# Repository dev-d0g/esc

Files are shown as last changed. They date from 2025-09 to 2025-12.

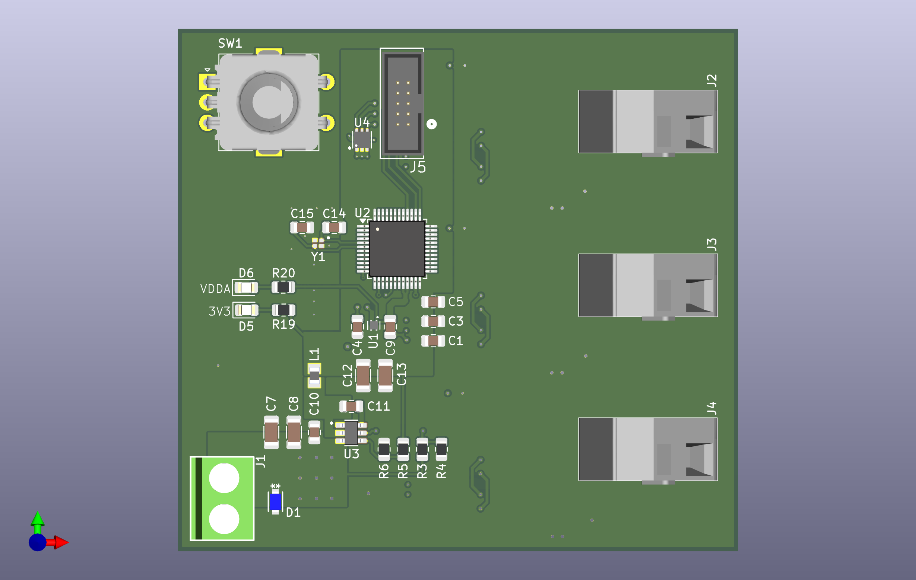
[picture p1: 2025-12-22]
top-view.png

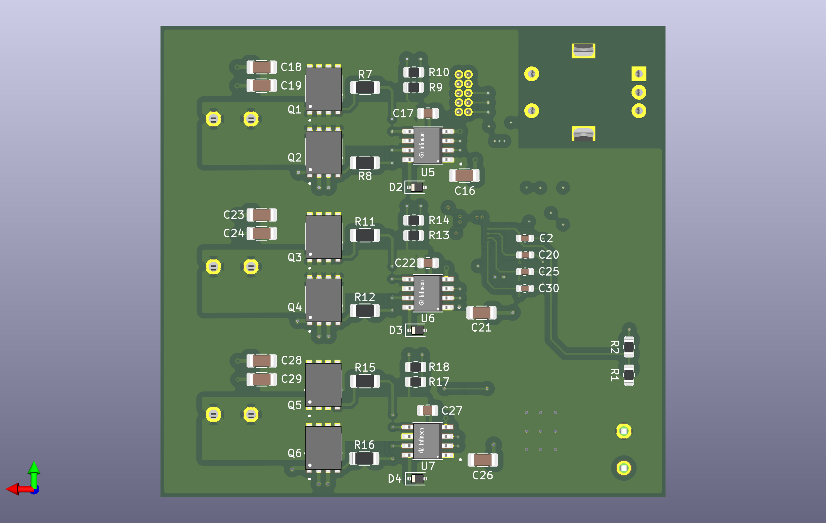
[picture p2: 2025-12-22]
bottom-view.png

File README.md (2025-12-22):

4 layer STM32-based trapezoidal ESC with high/low-side PWM control
top-view
bottom-view

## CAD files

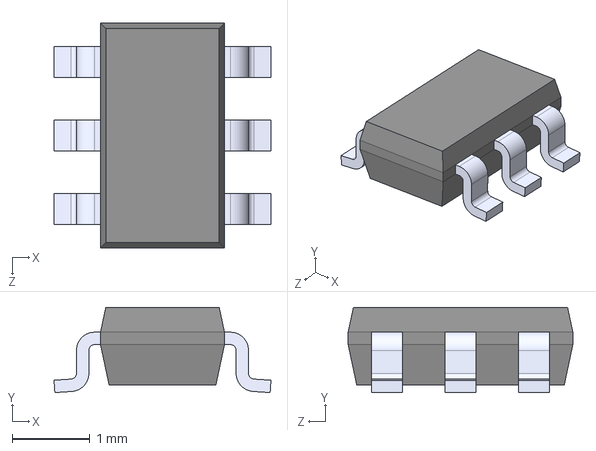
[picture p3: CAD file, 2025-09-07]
Digikey Downloads/Buck Converters/TPS562201DDCR/TPS562201DDCR.step
2.80 x 1.10 x 2.90 mm

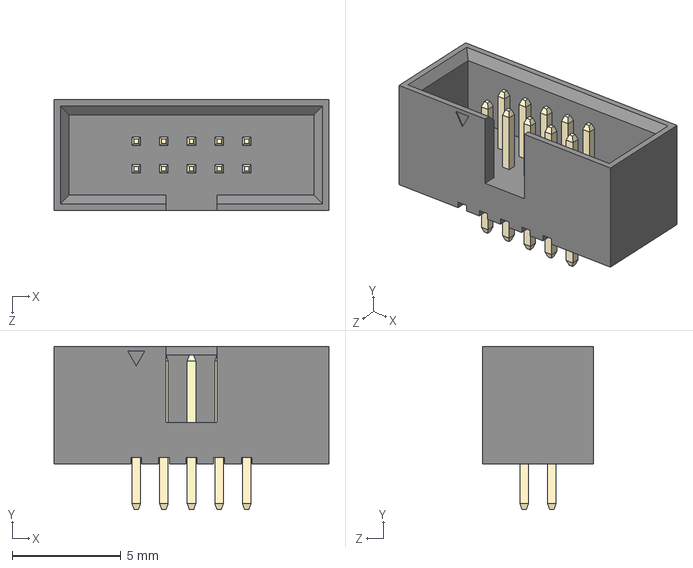
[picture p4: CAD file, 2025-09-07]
Digikey Downloads/Connectors/3220_10_0100_00_3D-model/3220-10-0100-00.STEP
12.7 x 7.50 x 5.10 mm
3220-xx-0100-00 body_10
Pin^3220-xx-0100-00 x 10

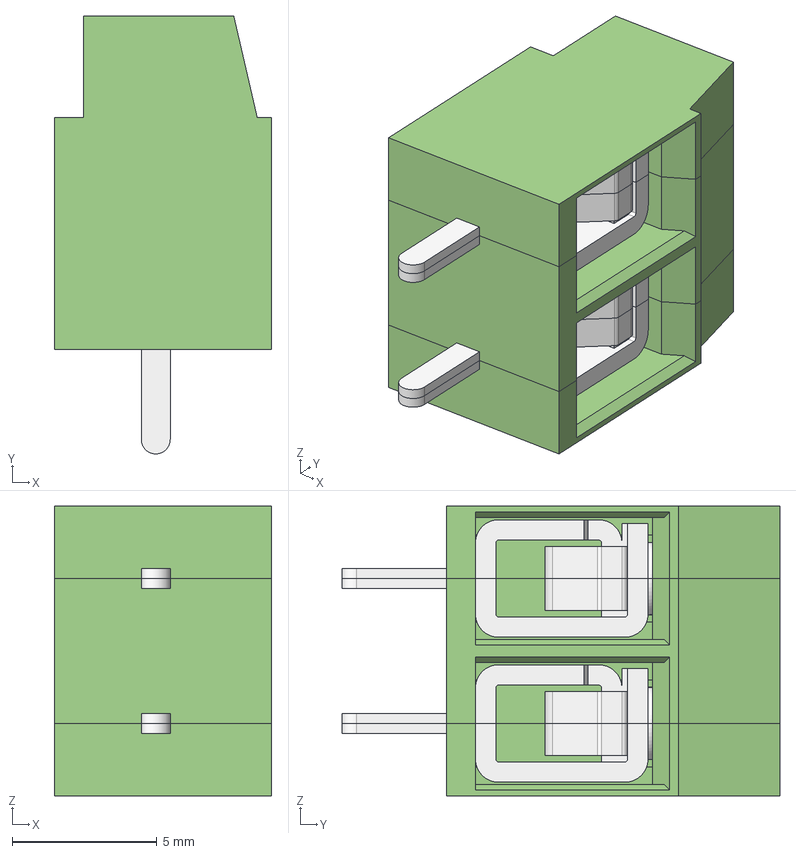
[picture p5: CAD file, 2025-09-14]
Digikey Downloads/Connectors/691137710002/691137710002.step
7.50 x 15.1 x 10.0 mm
MRT12P5_SX
MRT12P5_CNT
MRT12P5_DX

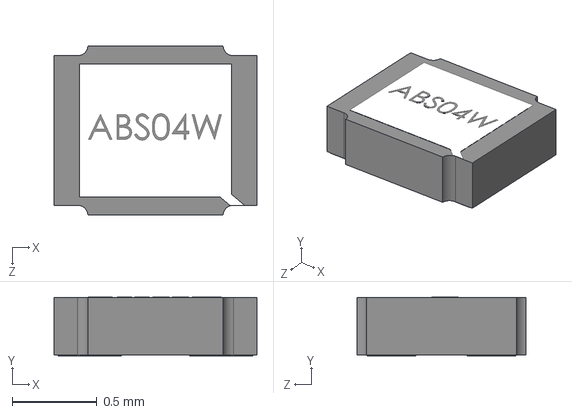
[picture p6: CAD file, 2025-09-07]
Digikey Downloads/Crystals/ABS04W_32_768KHZ_4_D2_T5/ABS04W-32.768KHZ-4-D2-T5.STEP
1.20 x 0.347 x 1.00 mm

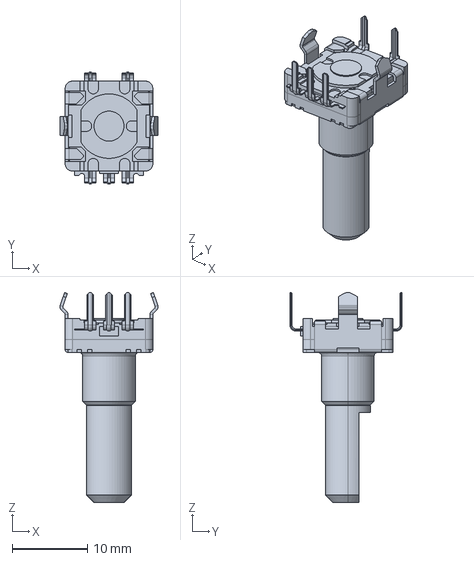
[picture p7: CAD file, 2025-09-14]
Digikey Downloads/Encoders/EC11E15204A3/ec11e15204a3.stp
13.1 x 15.0 x 28.0 mm

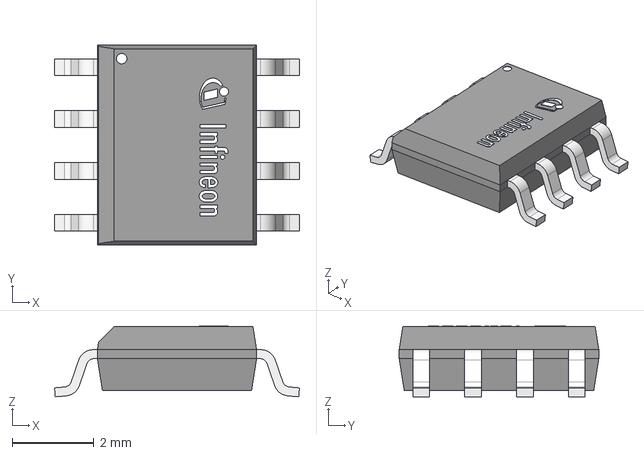
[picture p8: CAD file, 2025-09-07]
Digikey Downloads/Gate Drivers/IR2103STRPBF/PG-DSO-8-910.stp
6.00 x 4.89 x 1.73 mm

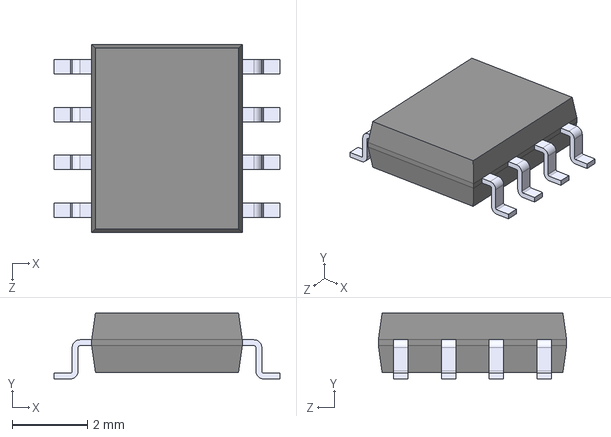
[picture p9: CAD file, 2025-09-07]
Digikey Downloads/Gate Drivers/IR2103STRPBF_Symbol-LandPattern/IR2103STRPBF.step
6.00 x 1.75 x 5.00 mm

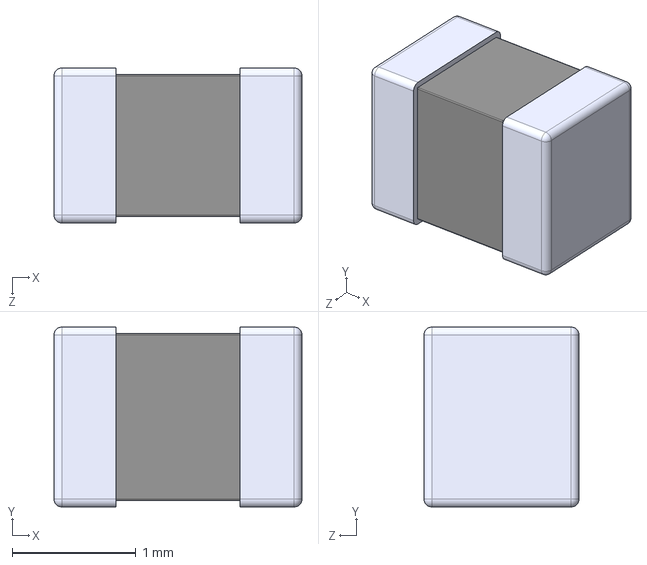
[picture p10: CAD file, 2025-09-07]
Digikey Downloads/Inductors/MLZ2012M3R3ATD69 (1)/MLZ2012M3R3ATD69.step
2.00 x 1.45 x 1.25 mm

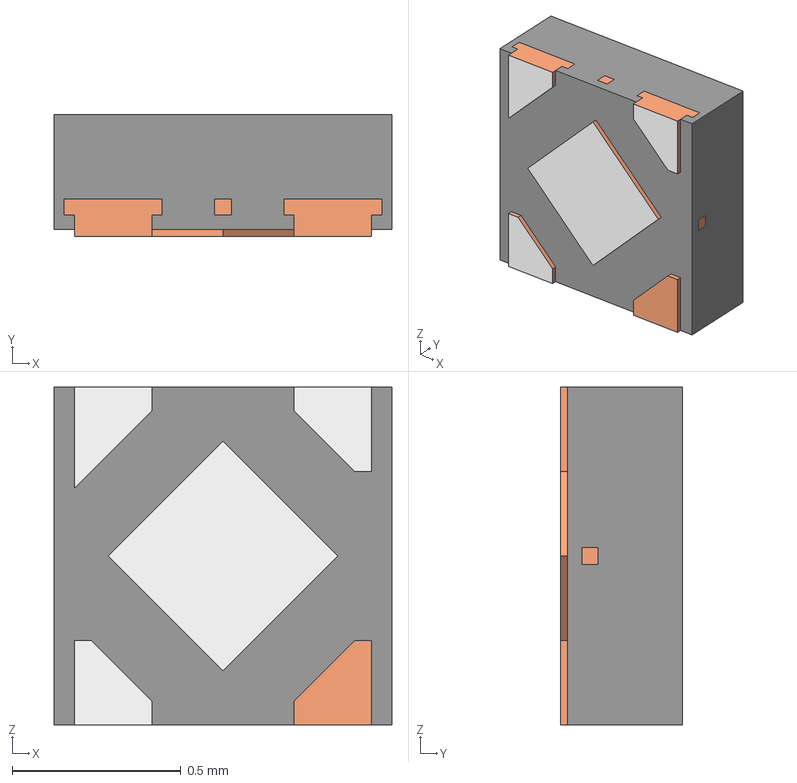
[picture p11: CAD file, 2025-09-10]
Digikey Downloads/LDOs/ul_PTPS7A20185PDQNR/DQN0004A.stp
1.00 x 0.36 x 1.00 mm
MOLD-SNB04A
FRAME-SNB04A

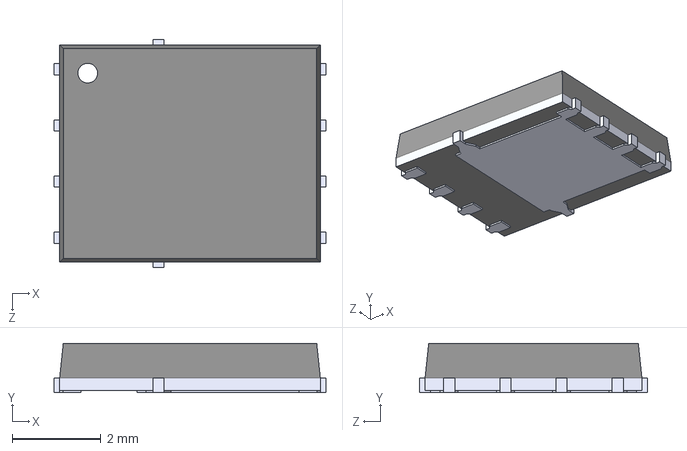
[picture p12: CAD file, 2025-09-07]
Digikey Downloads/MOSFETs/SIR182DP_T1_RE3 (1)/SIR182DP-T1-RE3.step
6.15 x 1.12 x 5.16 mm

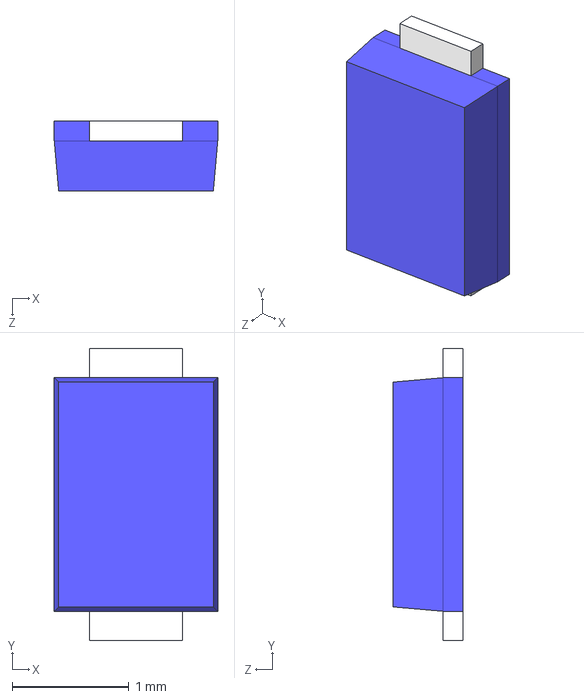
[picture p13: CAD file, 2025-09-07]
Digikey Downloads/TVS Diodes/CUHZ16V_H3F/US2H.STEP
1.40 x 2.50 x 0.6 mm

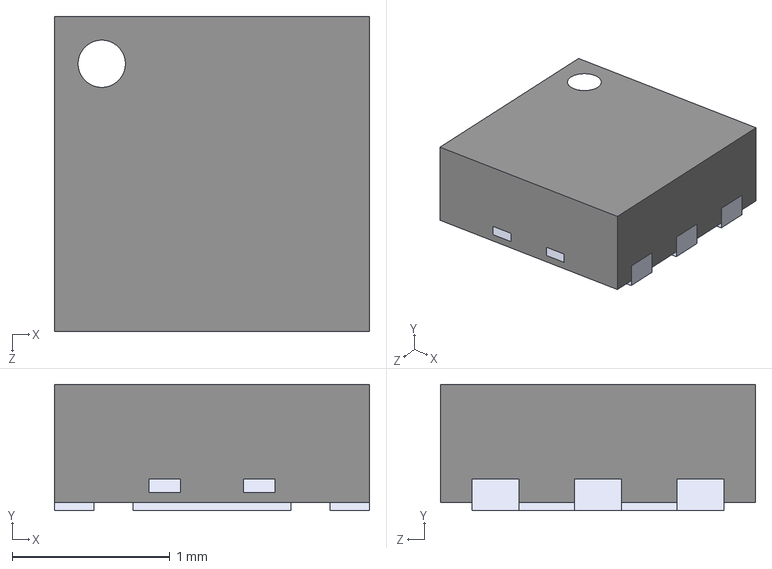
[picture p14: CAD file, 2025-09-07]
Digikey Downloads/TVS Diodes/TVS0500DRVR/TVS0500DRVR.step
2.00 x 0.8 x 2.00 mm

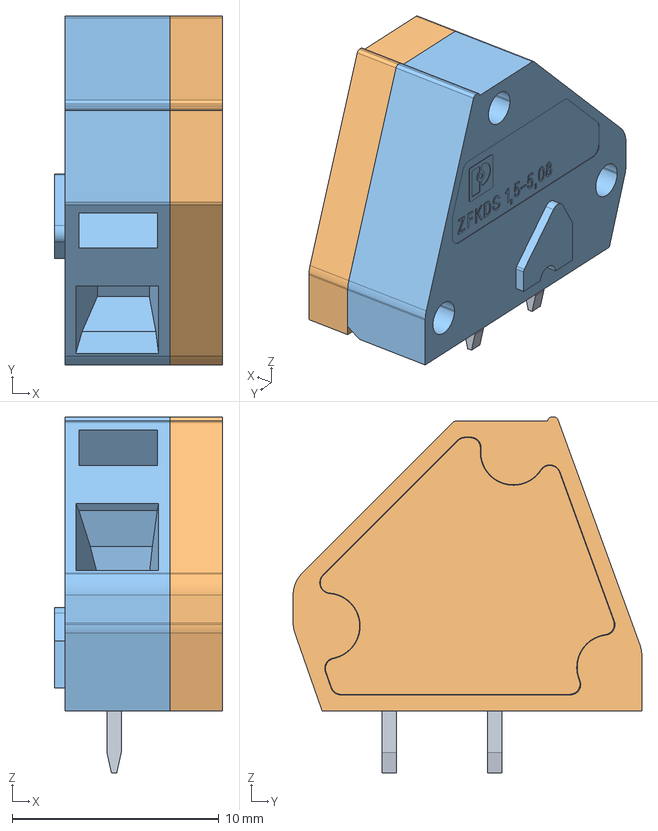
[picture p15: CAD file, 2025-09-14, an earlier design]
Digikey Downloads/Connectors/1706701 (1)/1706701.stp
8.12 x 16.9 x 17.2 mm

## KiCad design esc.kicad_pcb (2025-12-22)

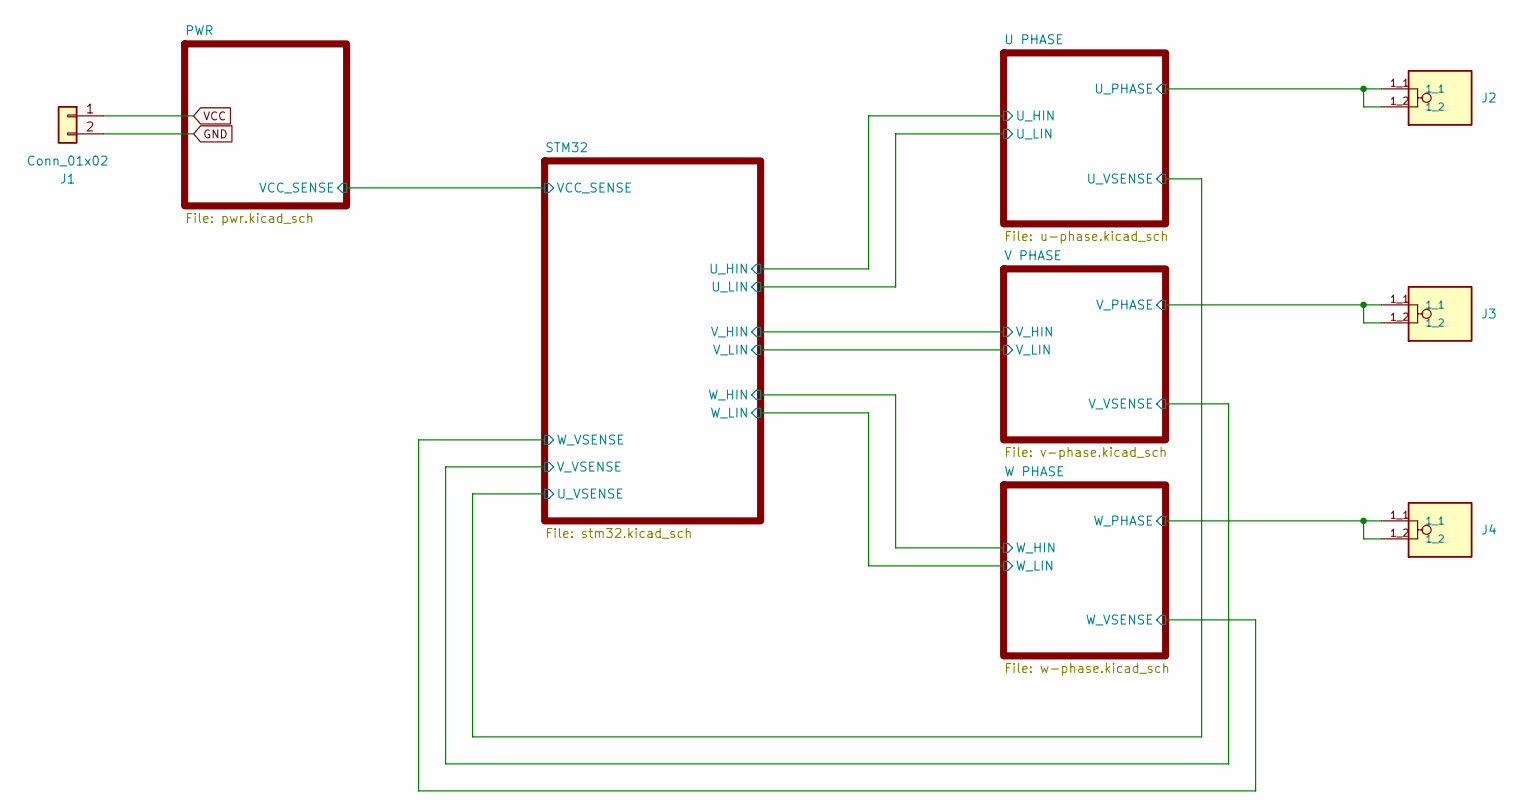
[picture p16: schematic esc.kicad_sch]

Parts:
J1: Conn_01x02; JWT_A3963_1x02_P3.96mm_Vertical
J2, J3, J4: Screw_Terminal_01x01; PHOENIX_1706701; PARTREV 24.09.2015

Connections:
/U PHASE/U_PHASE: J2.1_1, J2.1_2; also elsewhere on the board
/V PHASE/V_PHASE: J3.1_1, J3.1_2; also elsewhere on the board
/W PHASE/W_PHASE: J4.1_1, J4.1_2; also elsewhere on the board
GND: J1.2; also elsewhere on the board
VCC: J1.1; also elsewhere on the board

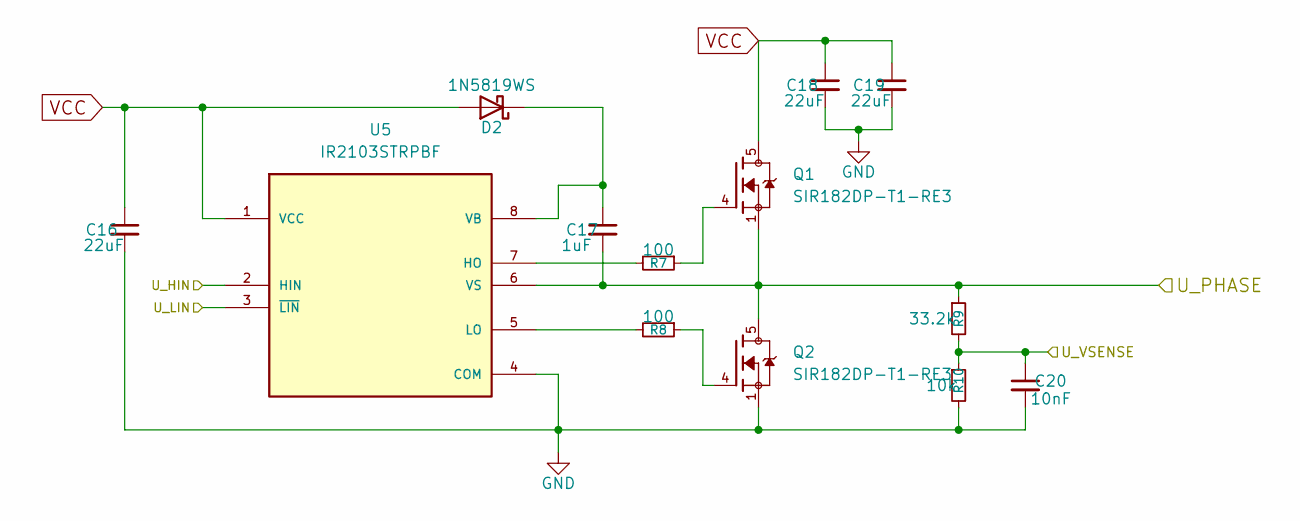
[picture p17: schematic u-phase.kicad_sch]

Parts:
C16, C18, C19: 22uF; C_1206_3216Metric
C17: 1uF; C_0805_2012Metric
C20: 10nF; C_0603_1608Metric
D2: 1N5819WS; D_SOD-323
Q1, Q2: SIR182DP-T1-RE3; TRANS_SIR182DP-T1-RE3; PARTREV B
R7, R8: 100; R_1206_3216Metric
R9: 33.2k; R_0805_2012Metric
R10: 10k; R_0805_2012Metric
U5: IR2103STRPBF; SOIC127P600X175-8N; PARTREV April 18, 2013

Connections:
/STM32/U_HIN: U5.2 (HIN); also elsewhere on the board
/STM32/U_LIN: U5.3 (~LIN); also elsewhere on the board
/STM32/U_VSENSE: C20.1, R9.2, R10.1; also elsewhere on the board
/U PHASE/U_PHASE: C17.2, Q1.1, Q1.2, Q1.3, Q2.5, Q2.6, Q2.7, Q2.8, Q2.9, R9.1, U5.6 (VS); also elsewhere on the board
GND: C16.2, C18.2, C19.2, C20.2, Q2.1, Q2.2, Q2.3, R10.2, U5.4 (COM); also elsewhere on the board
unnamed: C17.1, D2.1 (K), U5.8 (VB)
unnamed: Q1.4, R7.1
unnamed: Q2.4, R8.1
unnamed: R7.2, U5.7 (HO)
unnamed: R8.2, U5.5 (LO)
VCC: C16.1, C18.1, C19.1, D2.2 (A), Q1.5, Q1.6, Q1.7, Q1.8, Q1.9, U5.1 (VCC); also elsewhere on the board

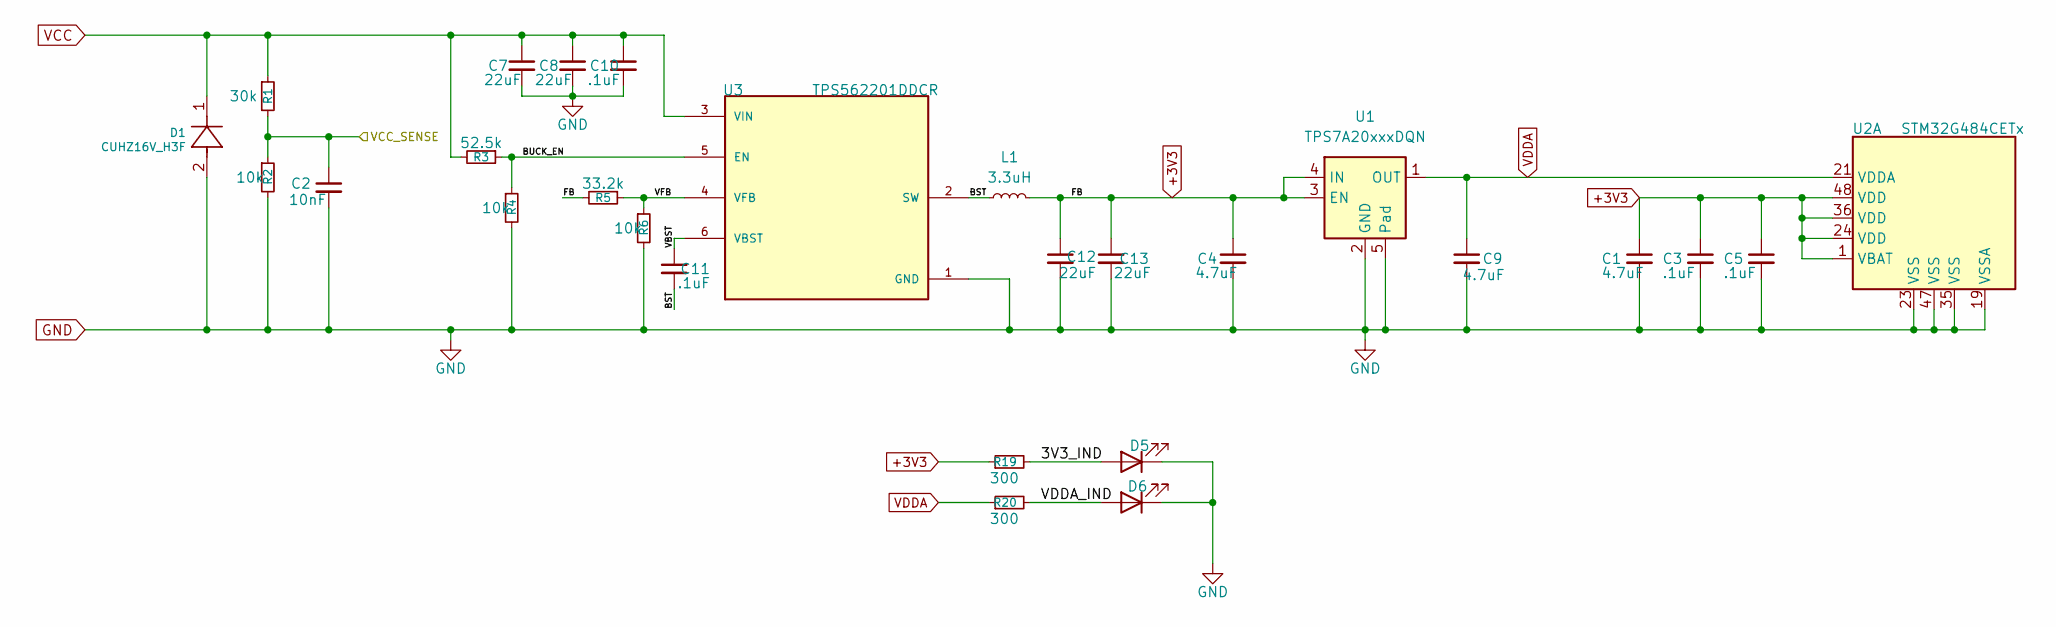
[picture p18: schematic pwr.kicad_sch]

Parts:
C1, C4, C9: 4.7uF; C_0805_2012Metric
C2: 10nF; C_0603_1608Metric
C3, C5, C10, C11: .1uF; C_0805_2012Metric
C7, C8, C12, C13: 22uF; C_1206_3216Metric
D1: CUHZ16V_H3F; SOD-323HEUS2H_TOS
D5, D6: LED; LED_0805_2012Metric
L1: 3.3uH; INDC2012X145N
R1: 30k; R_0805_2012Metric
R2, R4, R6: 10k; R_0805_2012Metric
R3: 52.5k; R_0805_2012Metric
R5: 33.2k; R_0805_2012Metric
R19, R20: 300; R_0805_2012Metric
U1: TPS7A20xxxDQN; Texas_X2SON-4_1x1mm_P0.65mm
U2: STM32G484CETx; LQFP-48_7x7mm_P0.5mm
U3: TPS562201DDCR; SOT95P280X110-6N; PARTREV A

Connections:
+3V3: C1.1, C3.1, C4.1, C5.1, C12.1, C13.1, L1.2, R5.2, R19.1, U1.3 (EN), U1.4 (IN), U2.1 (VBAT), U2.24 (VDD), U2.36 (VDD), U2.48 (VDD); also elsewhere on the board
/PWR/3V3_IND: D5.2 (A), R19.2
/PWR/BST: C11.2, L1.1, U3.2 (SW)
/PWR/BUCK_EN: R3.1, R4.1, U3.5 (EN)
/PWR/VBST: C11.1, U3.6 (VBST)
/PWR/VCC_SENSE: C2.1, R1.2, R2.1; also elsewhere on the board
/PWR/VDDA_IND: D6.2 (A), R20.2
/PWR/VFB: R5.1, R6.1, U3.4 (VFB)
GND: C1.2, C2.2, C3.2, C4.2, C5.2, C7.2, C8.2, C9.2, C10.2, C12.2, C13.2, D1.2, D5.1 (K), D6.1 (K), R2.2, R4.2, R6.2, U1.2 (GND), U1.5 (Pad), U2.19 (VSSA), U2.23 (VSS), U2.35 (VSS), U2.47 (VSS), U3.1 (GND); also elsewhere on the board
VCC: C7.1, C8.1, C10.1, D1.1, R1.1, R3.2, U3.3 (VIN); also elsewhere on the board
VDDA: C9.1, R20.1, U1.1 (OUT), U2.21 (VDDA); also elsewhere on the board

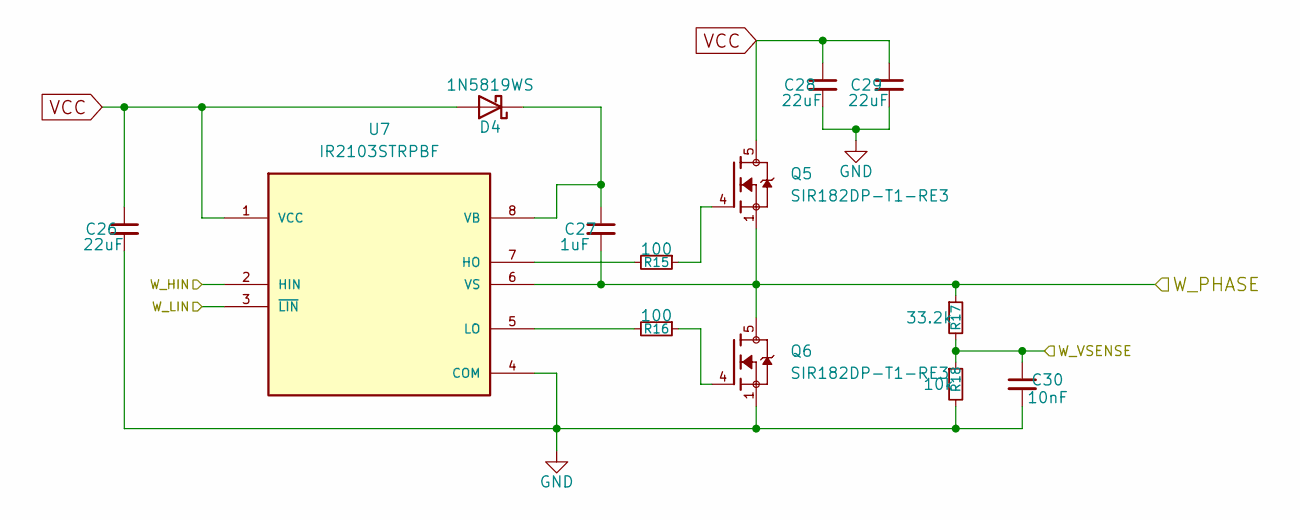
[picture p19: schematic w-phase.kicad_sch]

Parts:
C26, C28, C29: 22uF; C_1206_3216Metric
C27: 1uF; C_0805_2012Metric
C30: 10nF; C_0603_1608Metric
D4: 1N5819WS; D_SOD-323
Q5, Q6: SIR182DP-T1-RE3; TRANS_SIR182DP-T1-RE3; PARTREV B
R15, R16: 100; R_1206_3216Metric
R17: 33.2k; R_0805_2012Metric
R18: 10k; R_0805_2012Metric
U7: IR2103STRPBF; SOIC127P600X175-8N; PARTREV April 18, 2013

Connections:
/STM32/W_HIN: U7.2 (HIN); also elsewhere on the board
/STM32/W_LIN: U7.3 (~LIN); also elsewhere on the board
/STM32/W_VSENSE: C30.1, R17.2, R18.1; also elsewhere on the board
/W PHASE/W_PHASE: C27.2, Q5.1, Q5.2, Q5.3, Q6.5, Q6.6, Q6.7, Q6.8, Q6.9, R17.1, U7.6 (VS); also elsewhere on the board
GND: C26.2, C28.2, C29.2, C30.2, Q6.1, Q6.2, Q6.3, R18.2, U7.4 (COM); also elsewhere on the board
unnamed: C27.1, D4.1 (K), U7.8 (VB)
unnamed: Q5.4, R15.1
unnamed: Q6.4, R16.1
unnamed: R15.2, U7.7 (HO)
unnamed: R16.2, U7.5 (LO)
VCC: C26.1, C28.1, C29.1, D4.2 (A), Q5.5, Q5.6, Q5.7, Q5.8, Q5.9, U7.1 (VCC); also elsewhere on the board

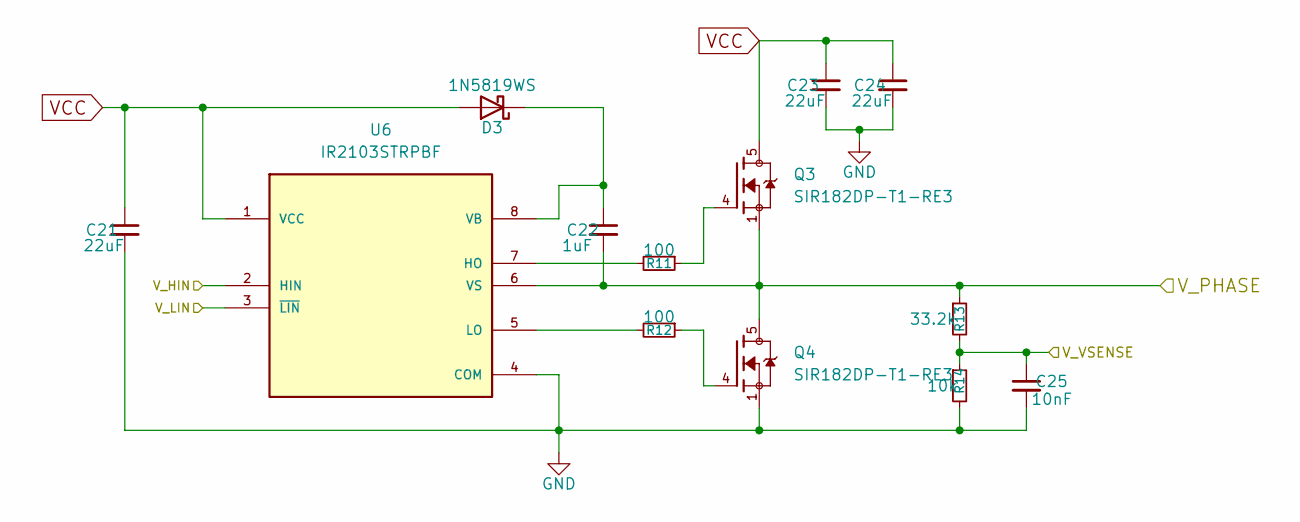
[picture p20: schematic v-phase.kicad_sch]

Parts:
C21, C23, C24: 22uF; C_1206_3216Metric
C22: 1uF; C_0805_2012Metric
C25: 10nF; C_0603_1608Metric
D3: 1N5819WS; D_SOD-323
Q3, Q4: SIR182DP-T1-RE3; TRANS_SIR182DP-T1-RE3; PARTREV B
R11, R12: 100; R_1206_3216Metric
R13: 33.2k; R_0805_2012Metric
R14: 10k; R_0805_2012Metric
U6: IR2103STRPBF; SOIC127P600X175-8N; PARTREV April 18, 2013

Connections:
/STM32/V_HIN: U6.2 (HIN); also elsewhere on the board
/STM32/V_LIN: U6.3 (~LIN); also elsewhere on the board
/STM32/V_VSENSE: C25.1, R13.2, R14.1; also elsewhere on the board
/V PHASE/V_PHASE: C22.2, Q3.1, Q3.2, Q3.3, Q4.5, Q4.6, Q4.7, Q4.8, Q4.9, R13.1, U6.6 (VS); also elsewhere on the board
GND: C21.2, C23.2, C24.2, C25.2, Q4.1, Q4.2, Q4.3, R14.2, U6.4 (COM); also elsewhere on the board
unnamed: C22.1, D3.1 (K), U6.8 (VB)
unnamed: Q3.4, R11.1
unnamed: Q4.4, R12.1
unnamed: R11.2, U6.7 (HO)
unnamed: R12.2, U6.5 (LO)
VCC: C21.1, C23.1, C24.1, D3.2 (A), Q3.5, Q3.6, Q3.7, Q3.8, Q3.9, U6.1 (VCC); also elsewhere on the board

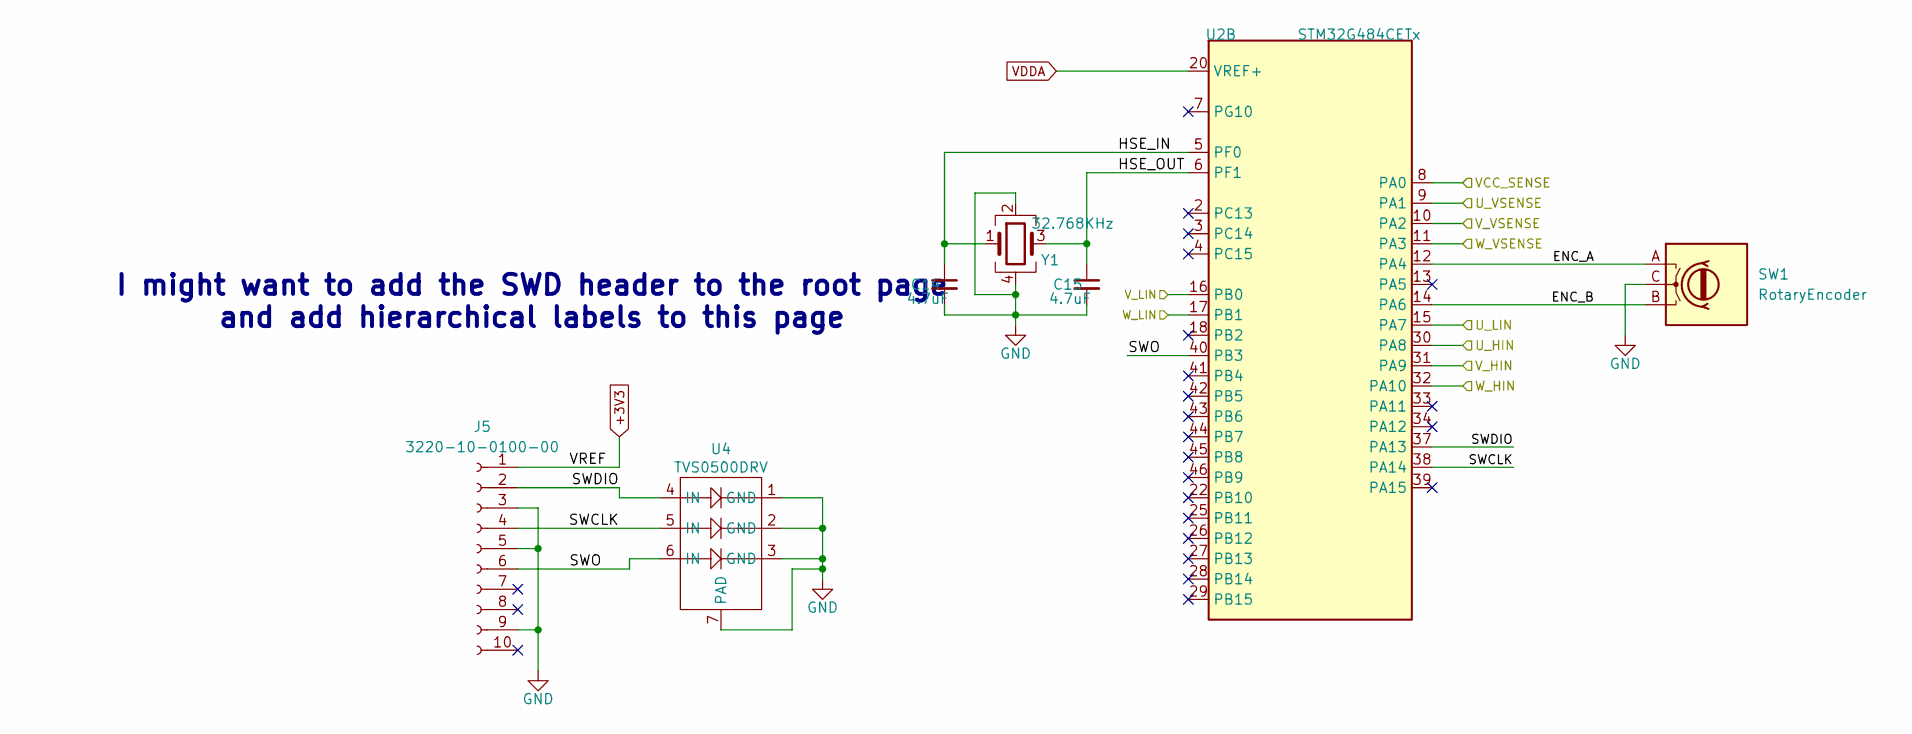
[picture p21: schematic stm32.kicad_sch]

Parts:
C14, C15: 4.7uF; C_0805_2012Metric
J5: 3220-10-0100-00; CONN_3220-10-0100-00_CNC
SW1: RotaryEncoder; RotaryEncoder_Alps_EC11E-Switch_Vertical_H20mm
U2: STM32G484CETx; LQFP-48_7x7mm_P0.5mm
U4: TVS0500DRV; SON65P200X200X80-7N
Y1: 32.768KHz; XTAL_ABS04W-32.768KHZ-4-D2-T5; PARTREV 12.18.2018

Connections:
+3V3: J5.1; also elsewhere on the board
/PWR/VCC_SENSE: U2.8 (PA0); also elsewhere on the board
/STM32/ENC_A: SW1.A, U2.12 (PA4)
/STM32/ENC_B: SW1.B, U2.14 (PA6)
/STM32/HSE_IN: C14.1, U2.5 (PF0), Y1.1
/STM32/HSE_OUT: C15.1, U2.6 (PF1), Y1.3
/STM32/SWCLK: J5.4, U2.38 (PA14), U4.5 (IN)
/STM32/SWDIO: J5.2, U2.37 (PA13), U4.4 (IN)
/STM32/SWO: J5.6, U2.40 (PB3), U4.6 (IN)
/STM32/U_HIN: U2.30 (PA8); also elsewhere on the board
/STM32/U_LIN: U2.15 (PA7); also elsewhere on the board
/STM32/U_VSENSE: U2.9 (PA1); also elsewhere on the board
/STM32/V_HIN: U2.31 (PA9); also elsewhere on the board
/STM32/V_LIN: U2.16 (PB0); also elsewhere on the board
/STM32/V_VSENSE: U2.10 (PA2); also elsewhere on the board
/STM32/W_HIN: U2.32 (PA10); also elsewhere on the board
/STM32/W_LIN: U2.17 (PB1); also elsewhere on the board
/STM32/W_VSENSE: U2.11 (PA3); also elsewhere on the board
GND: C14.2, C15.2, J5.3, J5.5, J5.9, SW1.C, U4.1 (GND), U4.2 (GND), U4.3 (GND), U4.7 (PAD), Y1.2, Y1.4; also elsewhere on the board
VDDA: U2.20 (VREF+); also elsewhere on the board

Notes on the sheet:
I might want to add the SWD header to the root page and add hierarchical labels to this page

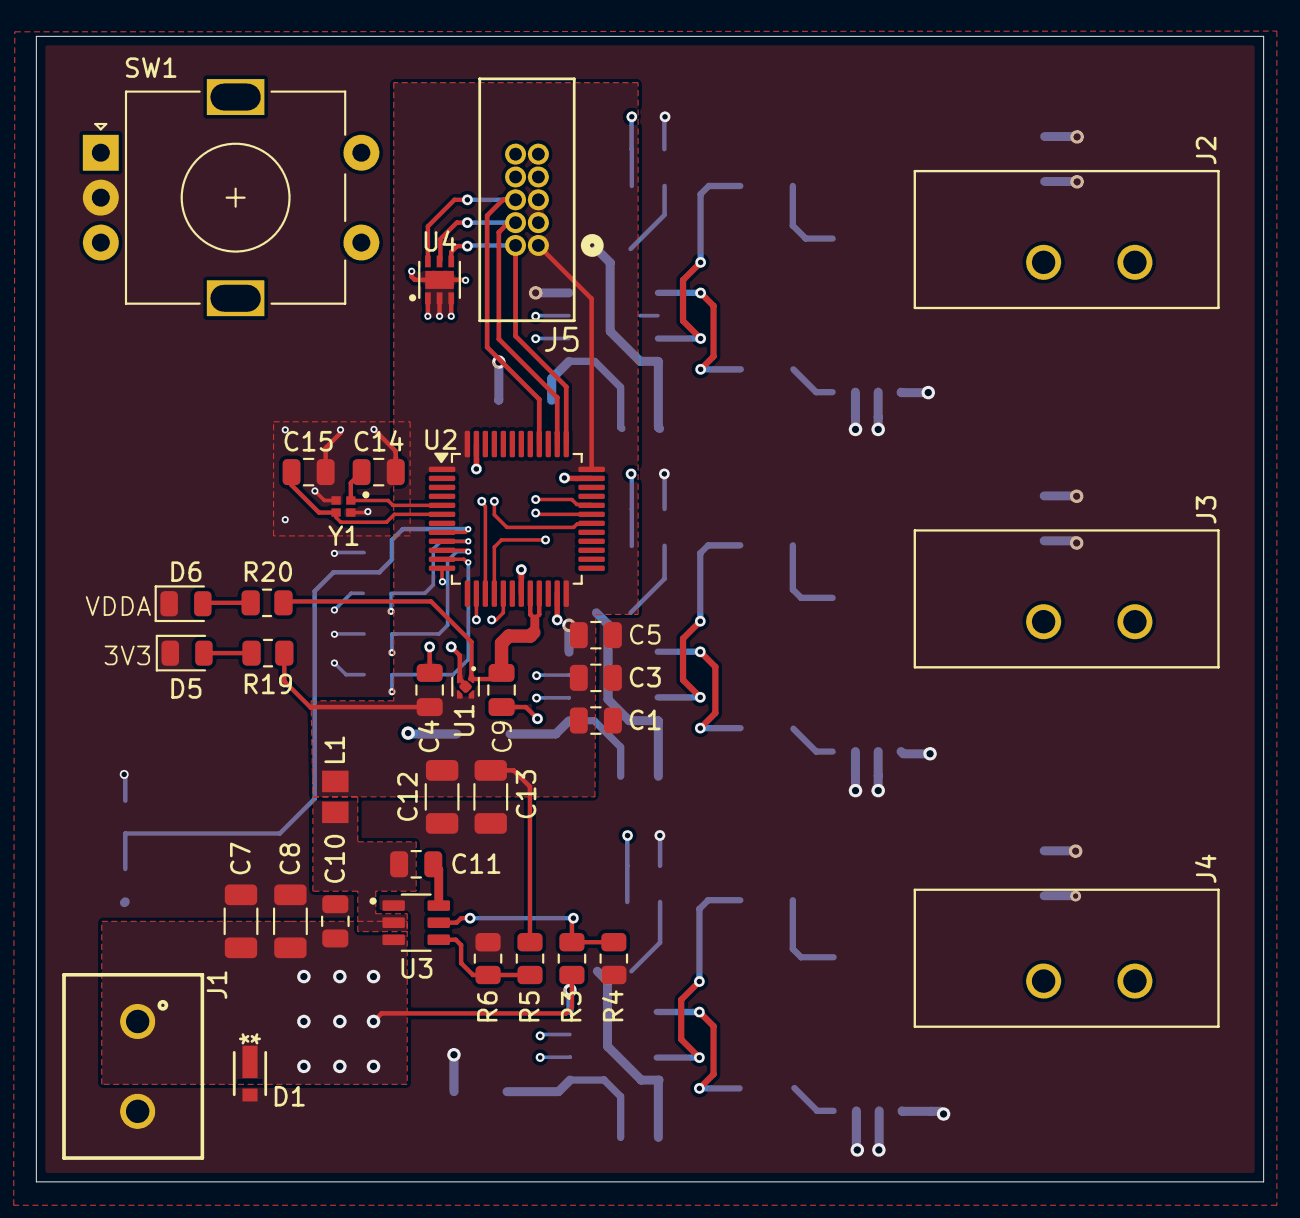
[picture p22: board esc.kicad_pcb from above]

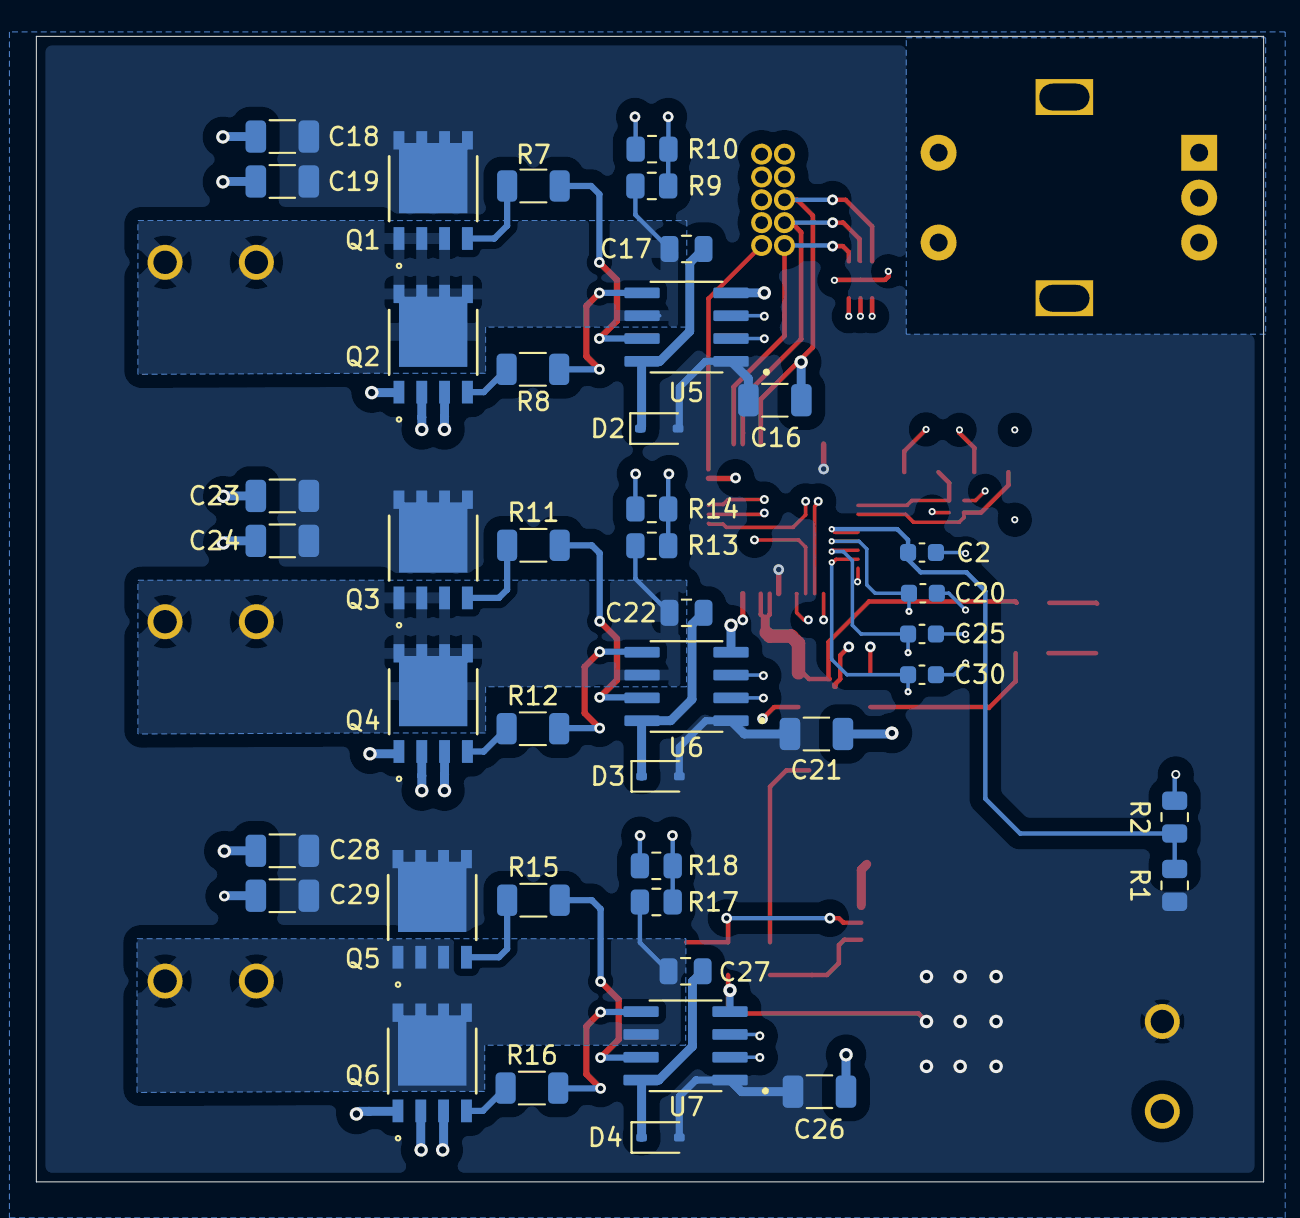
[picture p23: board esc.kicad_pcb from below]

Board: 4 copper layers, 68.3 x 63.8 mm, 76 parts (42 on the bottom side), 45 nets.

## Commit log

2025-09-07 Initial commit -- existing KiCad project
    [esc.kicad_pcb, esc.kicad_sch, pwr.kicad_sch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]
2025-09-07 Buck layout; MOSFET layout
    [esc.kicad_pcb, pwr.kicad_sch, stm32.kicad_sch]
2025-09-07 Added Digikey Downloads
    [3220-10-0100-00.STEP, ABS04W-32.768KHZ-4-D2-T5.STEP, ABS04W-32.768KHZ-4-D2-T5.step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]
2025-09-10 MOSFET placement
    [esc.kicad_pcb]
2025-09-10 Crystal routing/placement
    [DQN0004A.stp, esc.kicad_pcb]
2025-09-11 3V3 and VDDA placement
    [esc.kicad_pcb]
2025-09-13 PDN complete
    [esc.kicad_pcb, stm32.kicad_sch]
2025-09-14 completed layout -- DRC
    [1706701.stp, 691137710002.step, ec11e15204a3.stp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]
2025-09-18 cleaning up routing
    [esc.kicad_pcb]
2025-09-24 routing cleanup
    [esc.kicad_pcb]
2025-09-25 cleaning routing
    [esc.kicad_pcb]
2025-10-03 cleaning sensing routing
    [esc.kicad_pcb]
2025-10-19 SWD TVS routing
    [esc.kicad_pcb]
2025-10-19 DRC cleanup
    [esc.kicad_pcb]
2025-10-23 silkscreen cleanup
    [esc.kicad_pcb]
2025-12-21 improving MOSFET decap placements
    [esc.kicad_pcb, pwr.kicad_sch, stm32.kicad_sch]
2025-12-22 fab outputs
    [esc-B_Cu.gbl, esc-B_Mask.gbs, esc-B_Paste.gbp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]
